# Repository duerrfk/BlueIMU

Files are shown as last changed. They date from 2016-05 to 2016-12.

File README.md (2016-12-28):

# What is BlueIMU?

BlueIMU is an Inertial Measurement Unit (IMU) with 6 degrees of freedom and Bluetooth connectivity (serial port profile / SPP). 

The main features of BlueIMU are:

* Based on inexpensive, easily available hardware components, namely, the 6 degrees of freedom GY521 IMU module featuring an InvenSense MPU-6050 sensor, the HC06 Bluetooth module, and an Atmega328P microcontroller. 
* Runs from a single cell LiPo battery. An overdischarge protection is included in the design. 
* Raw sensor values can be transmitted at sampling rates of 200 Hz and higher through a 230400 Baud wireless serial connection (Bluetooth SPP).
* The BlueIMU software is based on the Arduino IDE and can be easily modified.
* Fully open source hardware (circuit board / PCB) and software design.
* Sample application with Kalman filter for calculating attitude (pitch and roll) included. 

The following image shows the BlueIMU board. The GY521 IMU module is the little blue board on the left; the green board is the HC06 Bluetooth module.

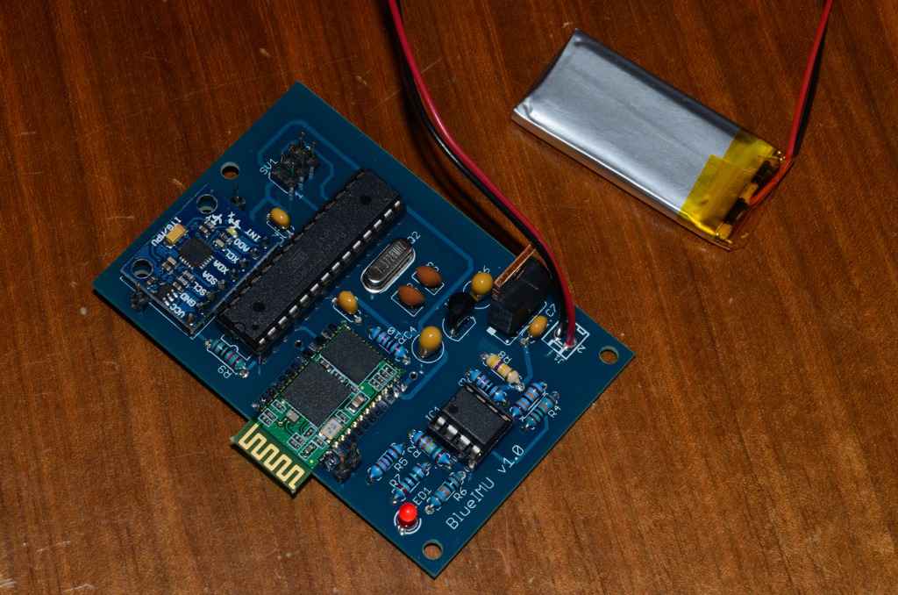
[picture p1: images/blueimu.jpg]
BlueIMU


Note that BlueIMU uses a 6 degrees of freedom IMU with a 3 axes accelerometer and 3 axes gyroscope, but without a magnetometer (compass). This is sufficient for sensing the pitch and roll, for instance, for controlling the attitude of a drone. However, we cannot sense the yaw to navigate a drone. However, the design could be easily adapted to use a 9 degrees of freedom IMU such as the InvenSense MPU-9250 on the GY-9250 module (GY521 and GY-9250 both use I2C for connecting to the MCU, but the GY-9250 requires 10 instead of 8 header pins to connect to the BlueIMU board).
 
# Why Yet Another IMU?

Many wireless IMUs today are based on Bluetooth Low Energy (BLE). Although BLE is optimized for very low energy consumption, it lacks support for higher data rates and low latency as required by sensors at higher sampling rates. In particular, the minimum connection interval of 7.5 ms inherently limits the sampling rate of wireless BLE sensors to about 133 Hz, and together with the small frames of only 20 bytes payload, the data rate is limited. Therefore, BLE is a great technology if you strive for years of battery lifetime at moderate data rates, however, for higher data rates and sensor sampling rates, standard Bluetooth is the better choice.

Therefore, BlueIMU uses standard Bluetooth supporting higher data rates (230400 Baud serial connection) to allow for higher sensor sampling rates at 200 Hz and higher.

# Hardware Design

The design of the BlueIMU circuit board (PCB) can be found in folder `pcb` (Eagle schematics and board design as well as Gerber files for production at a PCB house are included). 
  
BlueIMU is based on easily available low-cost components such as the GY521 IMU featuring a 6 degrees of freedom (3x accelerometer, 3x gyroscope) InvenSense MPU-6050 sensor, a HC06 Bluetooth module, and an Atmega328P microcontroller (MCU), which is well-supported by the popular Arduino platform.

The following images shows the schematic of the BlueIMU board.

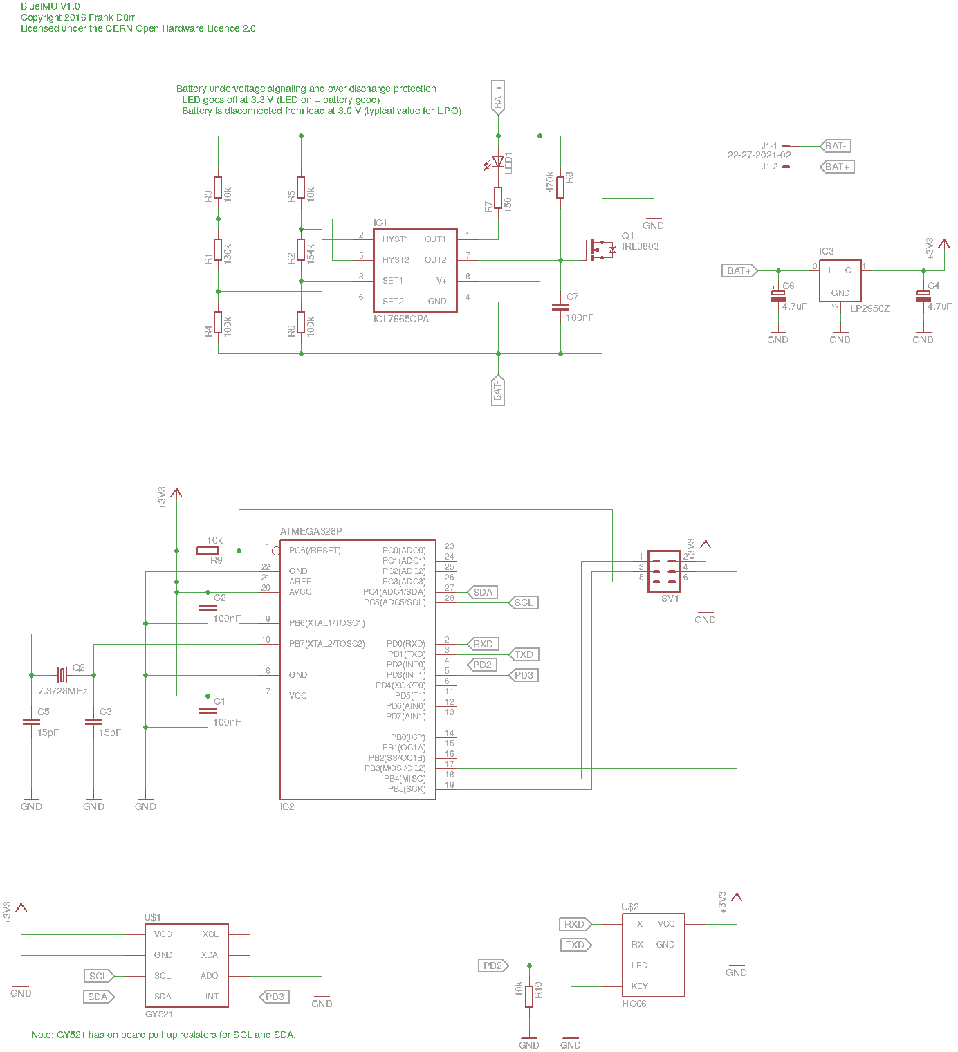
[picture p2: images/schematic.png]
Schematic


The Atmega328P MCU runs at 7.3728 MHz to allow for a perfect timing of the 230400 Baud serial connection to the HC06 Bluetooth module (230400 = 7.3728 MHz/32). Besides the serial connection, the HC06 module signals the Bluetooth connection state through a pin changing with a period of 750 ms while not connected and being constantly high while connected. Note that you need to porgram the HC06 module to use 230400 Baud using AT commands sent via the (wired) serial connection to the module (details can be found in the HC06 documentation).

A 6 pin connector is used to connect an in-system programmer with the following common pinout:

```
MISO <-- 1 2 --> VCC
SCK <--  3 4 --> MOSI
RST <--  5 6 --> GND
```

The GY521 module is connected through I2C to the MCU. It is soldered to the BlueIMU board using a 8 pin header providing for a rigid physical connection of the IMU to the BlueIMU board.

An overdischarge protection is included using the MAXIM ICL7665 voltage monitor. The MCU, IMU, and Bluetooth module will be disconnected from power at about 3.0 V. At about 3.3 V, the red LED (charge indicator) goes off to signal a low battery (the GY521 module has another onboard LED to show that the board is still running down to 3.0 V).  

## Preparing the Atmega328P (Programming Fuses)

Program the following fuses (note that "1" means fuse *not* programmed; "0" means fuse programmed):
  
* CKSEL = 1101, SUT 01: external crystal oscillator 3-8 MHz with fast startup times (BOD is enabled).
* CKDIV8 = 1: don't divide clock internally by 8.
* SPIEN = 0: enable serial programming.
* BODLEVEL = 101: brown-out detection set to 2.7 V.
* BOOTRST = 1: boot reset vector not enabled.
* RSTDISBL = 1: external reset not disabled.

This results in the following fuse bytes: 

* Low = 0xDD
* High = 0xD9
* Extended = 0x05

The MCU can be programmed using avrdude as follows:

```
$ sudo avrdude -c usbasp -p m328p -U lfuse:w:0xdd:m -U hfuse:w:0xd9:m -U efuse:w:0x05:m
```

## Flashing the Raw Transmitter Software

In folder `src/transmitter-raw` you find the raw transmitter software, which programs the BlueIMU to transmit raw measurements from the 3 axes accelerometer and 3 axes gyroscope of the MPU6050 IMU via Bluetooth serial profile (SPP). This software is implemented for the Arduino platform (tested with Arduino IDE 1.6.6) using the MPU6050 and I2C libraries by Jeff Rowberg.

In folder `arduino_board_definition` you find the corresponding board definition for the Atmega328P MCU running at 7.3728 MHz. Copy this directory into the folder `hardware` in your Arduino sketchbook.

Then, compile the Arduino sketch from folder `src/transmitter-raw`. This generates a hex file for the Atmega328P MCU. This hex file is a little bit hidden in the temporary build directory of the Arduino IDE. If you use Linux  and Arduino IDE 1.6, have a look at the `/tmp`  directory. After hitting the  compile button in the Arduino IDE, search for the latest hex file called  `transmitte-raw.cpp.hex` in a temporary directory named `/tmp/build...`. If you have found the hex file, you can flash it using avrdude:

```
$ sudo avrdude -p m328p -c usbasp -v -U flash:w:transmitter-raw.cpp.hex
```

## Data Format

Raw sensor data is transmitted over a Bluetooth serial connection. The transmitted data stream consists of records of the following format:

* Byte 0..1: Start of Record: 0x5A, 0xA5
* Byte 2..3: accelerometer X (16 bit signed int)  
* Byte 4..5: accelerometer Y (16 bit signed int)
* Byte 6..7: accelerometer Z (16 bit signed int)
* Byte 8..9: gyro X (16 bit signed int)
* Byte 10..11: gyro Y (16 bit signed int)
* Byte 12..13: gyro Z (16 bit signed int)
* Byte 14..17: sample time stamp (32 bit unsigned integer) in milliseconds since boot time
* Byte 18..19: 16 bit checksum

All 16 bit words are transmitted in Big Endian format (high byte first, low byte second). 

## Interpreting Raw Values

Values from sensors are transmitted as raw signed 16 bit values. The values can be translated to g and deg/s, respectively, depending on the configured sensor sensitivities (+-2g, +-4g, +-8g, +-16g; +-250 deg/s, +-500 deg/s, +- 1000 deg/s, +-2000 deg/s). The following resolutions are supported by the MPU6050 IMU:

* accelerometer: 16384, 8192, 4096, 2048 LSB / g
* gyro: 131, 65.5, 32.8, and 16.5 LSB / (deg/s) 

Please have a look at the manual of the MPU6050 for further details.

## Checksum 

The checksum consists of the ones' complement of the ones' complement sum of the 16-bit words, similar to the calculation of the checksum of IP headers. For detailed information on how to calculate the checksum, please have a look at the code. 

## Sampling Rate

The sampling rate can be adjusted by the SAMPLING_PERIOD definition.

## Low-pass Filter

The MPU 6050 features a low-pass filter. You can set the filter by defining DLPF according to the following table:

             |   ACCELEROMETER    |           GYROSCOPE
    DLPF_CFG | Bandwidth | Delay  | Bandwidth | Delay  | Sample Rate
    ---------+-----------+--------+-----------+--------+-------------
    0        | 260Hz     | 0ms    | 256Hz     | 0.98ms | 8kHz
    1        | 184Hz     | 2.0ms  | 188Hz     | 1.9ms  | 1kHz
    2        | 94Hz      | 3.0ms  | 98Hz      | 2.8ms  | 1kHz
    3        | 44Hz      | 4.9ms  | 42Hz      | 4.8ms  | 1kHz
    4        | 21Hz      | 8.5ms  | 20Hz      | 8.3ms  | 1kHz
    5        | 10Hz      | 13.8ms | 10Hz      | 13.4ms | 1kHz
    6        | 5Hz       | 19.0ms | 5Hz       | 18.6ms | 1kHz
    7        |   -- Reserved --   |   -- Reserved --   | Reserved

# Connecting a Linux Host to BlueIMU over Bluetooth

You can connect a Linux host to the BlueIMU board via Bluetooth as follows:

Step 1: Find the BlueIMU device 

```
$ hcitool scan
Scanning ...
	00:11:12:31:04:12	BlueIMU
```

Step 2: Pairing Linux host and BlueIMU device:

```
$ bluetooth-agent 1234 00:11:12:31:04:12
```

Step 3: Add device profile

```
$ sudo nano /etc/bluetooth/rfcomm.conf
```

Add the following section:

```
rfcomm1 {
  bind no;
  device 00:11:12:31:04:12;
  channel 1;
  comment "Blue IMU serial Port";
}
```

Connect host to BlueIMU device: 

```
$ rfcomm connect 1
```

Now, you should have a serial device called `/dev/rfcomm1` that you can open with your application. For instance, you can use screen to log data as follows:

```
$ screen -L /dev/rfcomm1
```

# Kalman Filter

In folder `src/receiver-attitude` you find a sample application for Linux implementing a Kalman filter to calculate the attitude (pitch and roll) and logging raw sensor values and Kalman filter values (pitch, roll, estimated gyro bias) to a file as comma-separate values. Note that the GY521 IMU does not feature a magnetometer (compass), thus, we cannot easily detect the absolute heading (yaw). 

You can compile this application with the following commands:

```
$ cd src/receiver-attitude
$ make 
```

Then you start it as follows:

```
$ ./receiver-attitude -d /dev/rfcomm1 -o out.csv
```

The Kalman filter uses the following equations:

State vector (phi is the angle; phidot is the angular velocity; bias is the bias of angular velocity (gyro bias)): 

```
    [ phi  ] 
x = [phidot]
    [ bias ] 
```

State equation:

```
x(k) = F(k)*x(k-1) + omega(k)
```

with

```
       [1 t_delta -t_delta]
F(k) = [0    1        0   ]
       [0    0        1   ]
```

This implementation assumes no control input model (B). Instead, a normally distributed random angular acceleration (phidotdot) is introduced modeling the effect of external forces like motors as part of the random process noise (omega):

```
           [t_delta**2/2]
omega(k) = [  t_delta   ] * phidotdot
           [     0      ]
```

Covariance matrix Q of normally distributed random process noise omega ~ N(0,Q):

```
Q = G*Gtrans*sigma_phidotdot**2 

    [t_delta**4/4  t_delta**3/2  0]                        [ 0 0 0 ]
  = [t_delta**3/2   t_delta**2   0] * sigma_phidotdot**2 + [ 0 0 0 ] * sigma_bias**2 
    [      0             0       0]                        [ 0 0 1 ]
```

Moreover, we assume that we can measure the angle from the IMU acceleration (phi_m) and the angular velocity (phidot_m) from the gyroscope. However, we cannot measure the gyro bias. Measurements are modeled as independent normally distributed random variables to account for measurement noise. The covariance matrix R of normally distributed random measuring noise v ~ N(0,R) is defined as:

```
    [sigma_phi_m**2         0         ]
R = 
    [     0          sigma_phidot_m**2]
```

Sample data of a stationary IMU and an IMU attached to a pendulum can be found in folder `sample-data`. 

The following plot shows the angle of a pendulum in radians over time as calculated by the Kalman filter:

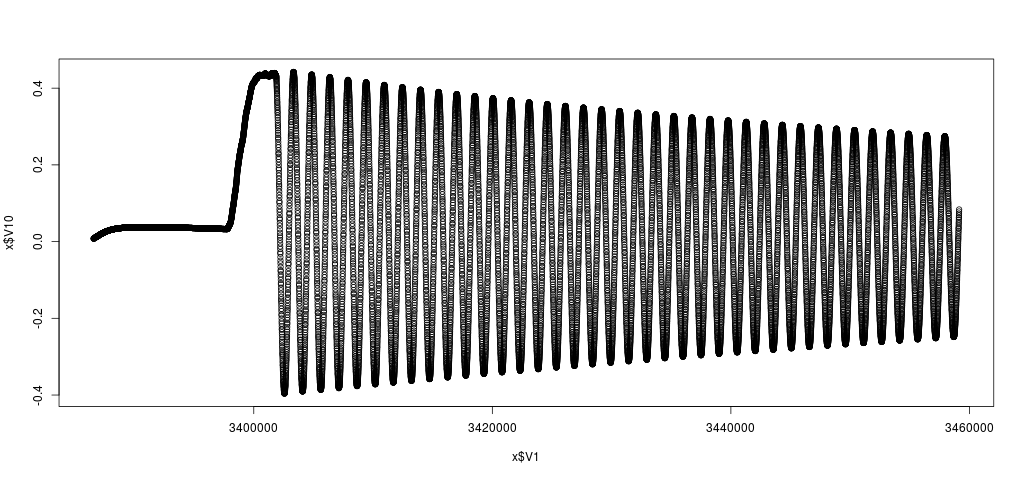
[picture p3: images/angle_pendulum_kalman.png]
Angle pendulum Kalman


As a comparison, here the angle in radians over time calculated directly from the accelerometer without Kalman filter, i.e., without fusing measurements from accelerometer and gyroscope:

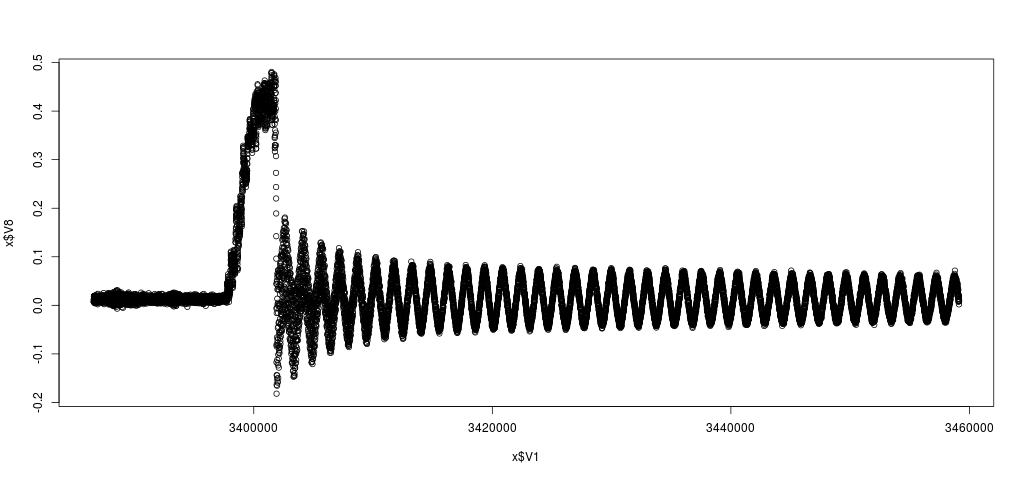
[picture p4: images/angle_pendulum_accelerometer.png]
Angle pendulum accelerometer


Observer how the angle calculated just from acceleration is only correct while the object is at rest and clearly wrong when the pendulum moves such that gravity cannot be easily distinguished anymore from the acceleration caused by centripetal force. In that case, the Kalman filter can use the angular velocity to predict the angle leading to much more accurate results.

# License

The BlueIMU software (contents of folders `src`) is licensed under the Apache License, Version 2.0.

The BlueIMU hardware documentation (contents of folder `pcb`) is licensed under the CERN Open Hardware Licence, Version 1.2

Both licenses are included in the repository in the files `LICENSE-SOFTWARE` and `LICENSE-HARDWARE`, respectively.

The BlueIMU software uses the I2Cdev device library and MPU-6050 code by Jeff Rowberg licensed under the MIT license.

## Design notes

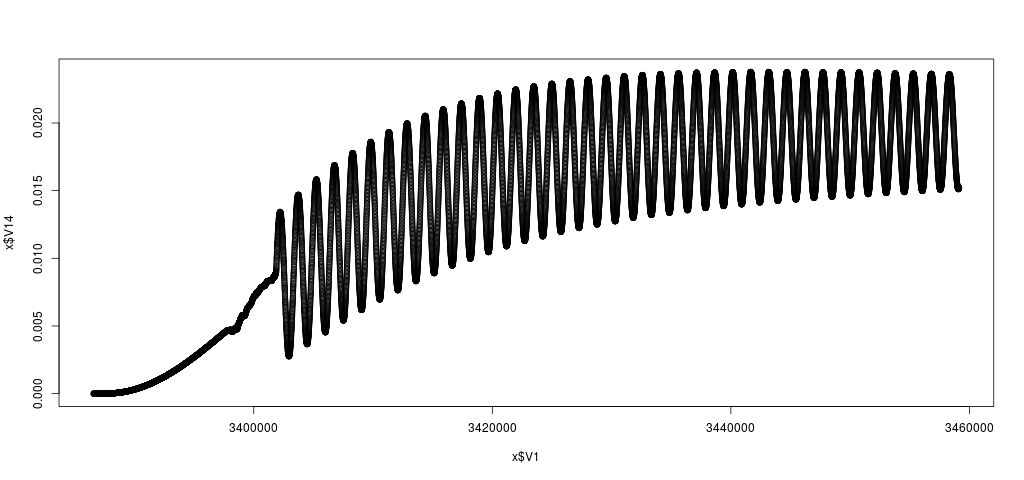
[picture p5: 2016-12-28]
images/gyro_bias_pendulum.png

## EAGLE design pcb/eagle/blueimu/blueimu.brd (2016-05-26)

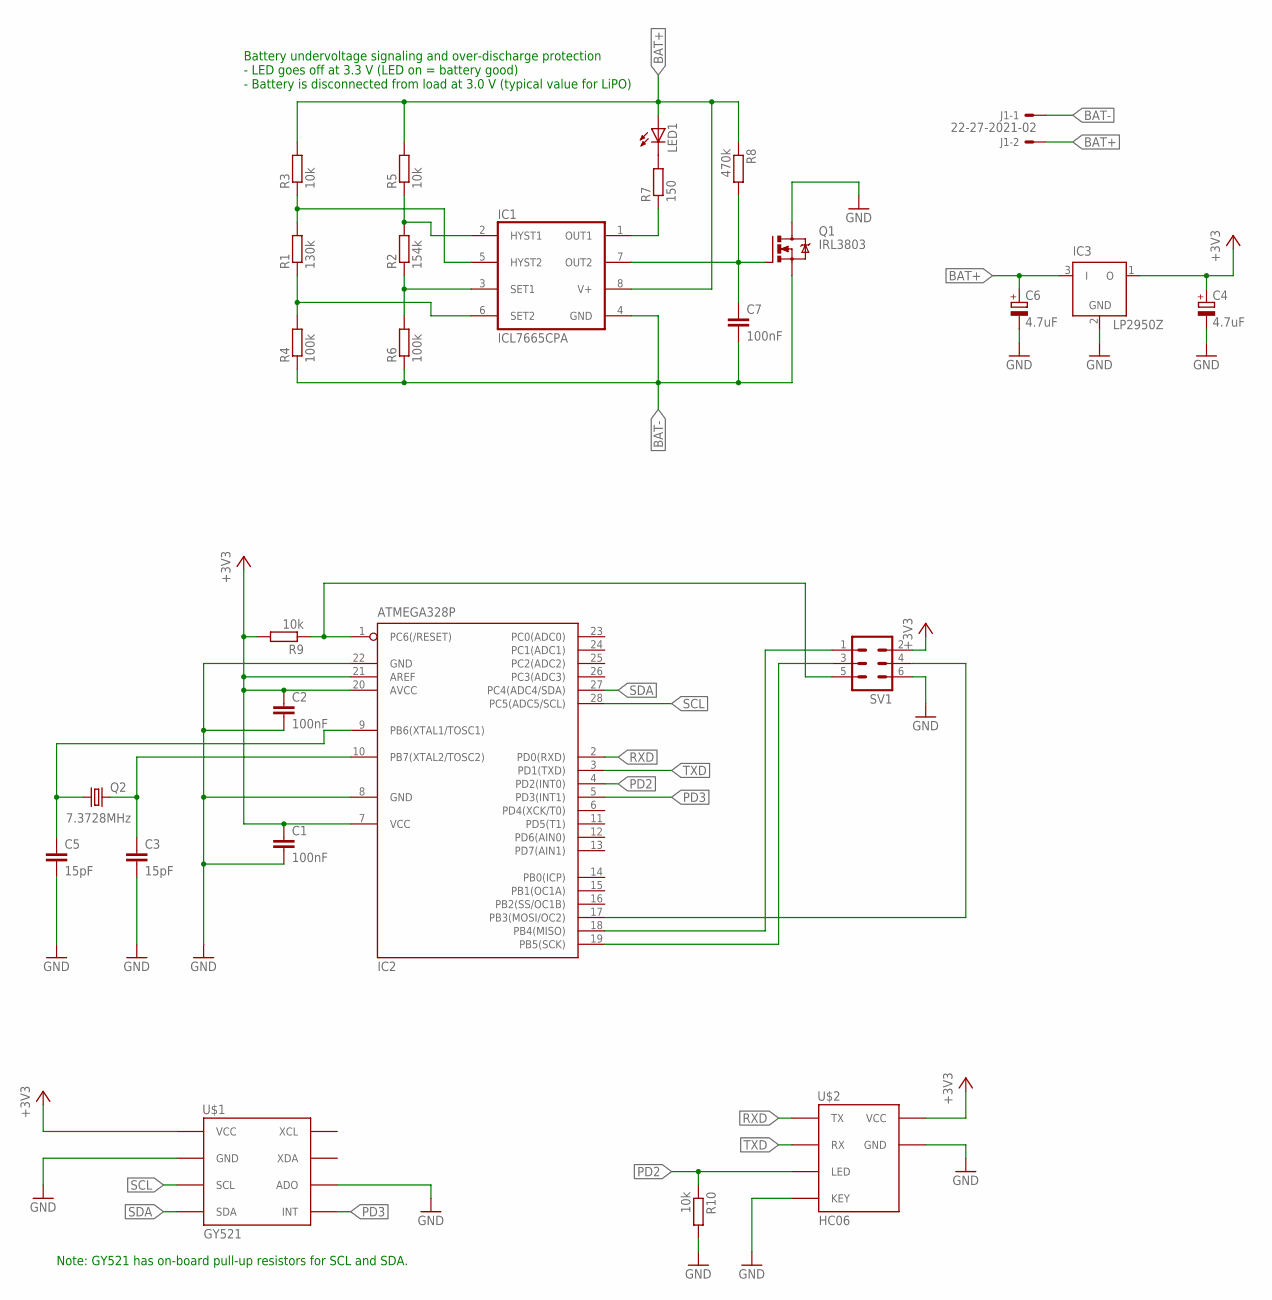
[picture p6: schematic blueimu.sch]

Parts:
C1, C2, C7: 100nF; C050-024X044
C3, C5: 15pF; C025-025X050
C4, C6: 4.7uF; E2,5-5
IC1: ICL7665CPA; DIL08
IC2: ATMEGA328P; DIL28-3
IC3: LP2950Z; TO92
J1: 22-27-2021-02; 6410-02
LED1: LED3MM
Q1: IRL3803; TO220BV
Q2: 7.3728MHz; HC49U-V
R1: 130k; 0207/7
R2: 154k; 0207/7
R3, R5, R9, R10: 10k; 0207/7
R4, R6: 100k; 0207/7
R7: 150; 0207/7
R8: 470k; 0207/7
SV1: MA03-2
U$1: GY521
U$2: HC06

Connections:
+3V3: C1.1, C2.1, C4.+, IC2.7 (VCC), IC2.20 (AVCC), IC2.21 (AREF), IC3.1 (O), R9.2, SV1.2, U$1.VCC, U$2.VCC
BAT+: C6.+, IC1.8 (V+), IC3.3 (I), J1.2, LED1.A, R3.2, R5.2, R8.1
BAT-: C7.2, IC1.4 (GND), J1.1, Q1.S, R4.1, R6.1
GND: C1.2, C2.2, C3.2, C4.-, C5.2, C6.-, IC2.8 (GND), IC2.22 (GND), IC3.2 (GND), Q1.D, R10.2, SV1.6, U$1.ADO, U$1.GND, U$2.GND, U$2.KEY
unnamed: LED1.K (C), R7.2
unnamed: IC1.1 (OUT1), R7.1
unnamed: IC1.2 (HYST1), R2.2, R5.1
unnamed: IC1.3 (SET1), R2.1, R6.2
unnamed: IC2.18 (PB4(MISO)), SV1.1
unnamed: IC2.19 (PB5(SCK)), SV1.3
unnamed: IC2.17 (PB3(MOSI/OC2)), SV1.4
unnamed: IC2.1 (PC6(/RESET)), R9.1, SV1.5
unnamed: C7.1, IC1.7 (OUT2), Q1.G, R8.2
unnamed: C3.1, IC2.10 (PB7(XTAL2/TOSC2)), Q2.2
unnamed: IC1.6 (SET2), R1.1, R4.2
unnamed: IC1.5 (HYST2), R1.2, R3.1
unnamed: C5.1, IC2.9 (PB6(XTAL1/TOSC1)), Q2.1
PD2: IC2.4 (PD2(INT0)), R10.1, U$2.LED
PD3: IC2.5 (PD3(INT1)), U$1.INT
RXD: IC2.2 (PD0(RXD)), U$2.TX
SCL: IC2.28 (PC5(ADC5/SCL)), U$1.SCL
SDA: IC2.27 (PC4(ADC4/SDA)), U$1.SDA
TXD: IC2.3 (PD1(TXD)), U$2.RX

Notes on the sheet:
Note: GY521 has on-board pull-up resistors for SCL and SDA.
Battery undervoltage signaling and over-discharge protection - LED goes off at 3.3 V (LED on = battery good) - Battery is disconnected from load at 3.0 V (typical value for LiPO)

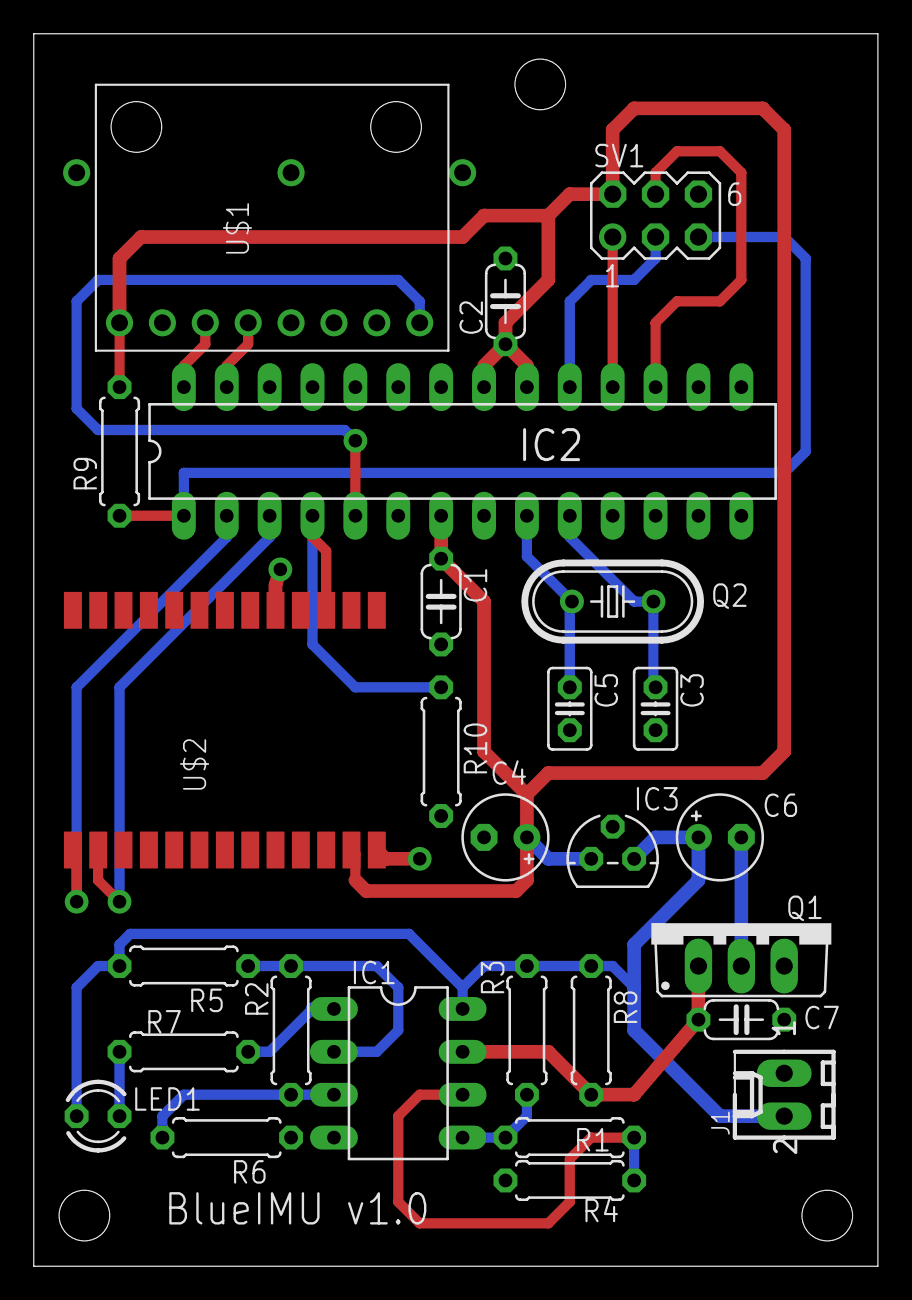
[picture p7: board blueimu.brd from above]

Board: 2 copper layers, 50.0 x 73.0 mm, 27 parts (0 on the bottom side), 23 nets.

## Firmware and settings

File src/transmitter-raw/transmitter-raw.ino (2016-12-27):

/**
 * This file is part of BlueIMU.
 * 
 * Copyright 2016 Frank Duerr
 *
 * Licensed under the Apache License, Version 2.0 (the "License");
 * you may not use this file except in compliance with the License.
 * You may obtain a copy of the License at
 * 
 * http://www.apache.org/licenses/LICENSE-2.0
 * 
 * Unless required by applicable law or agreed to in writing, software
 * distributed under the License is distributed on an "AS IS" BASIS,
 * WITHOUT WARRANTIES OR CONDITIONS OF ANY KIND, either express or implied.
 * See the License for the specific language governing permissions and
 * limitations under the License.
 */
 
#include <TimerOne.h>
#include <Wire.h>
#include "I2Cdev.h"
#include "MPU6050.h"

// The pin where the LED output of the Bluetooth module is connected.
// This pin is used to detect the connection status (blinking = disconnected;
// constantly on = connected). This pin supports level interrupts to listen 
// for connection status changes.
#define PIN_LED 2

// Sampling period in microseconds.
// Note: Depending on the sampling interval, you should set the digital 
// low-pass filter. Filter cut-off frequencies should not be too low for 
// a given sampling period (see DLPF definition).
#define SAMPLING_PERIOD 5000

// The baud rate of the serial connection to the Bluetooth module. 
// The MCU is running at 7.3728 MHz. Thus, 230400 baud = 7.3728/32 allows for 
// perfect timing for serial communication. 
#define BAUD_RATE 230400

// The sensitivity and value range of the accelerometer as defined by the
// following table:
//
// AFS_SEL | Full Scale Range | LSB Sensitivity
// --------+------------------+----------------
// 0       | +/- 2g           | 16384 LSB/g
// 1       | +/- 4g           | 8192 LSB/g
// 2       | +/- 8g           | 4096 LSB/g
// 3       | +/- 16g          | 2048 LSB/g
#define RANGE_ACCEL 1

// The sensitivity and value range of the gyroscope as defined by the
// following table:
//
// FS_SEL | Full Scale Range   | LSB Sensitivity
// -------+--------------------+----------------
// 0      | +/- 250 degrees/s  | 131 LSB/deg/s
// 1      | +/- 500 degrees/s  | 65.5 LSB/deg/s
// 2      | +/- 1000 degrees/s | 32.8 LSB/deg/s
// 3      | +/- 2000 degrees/s | 16.4 LSB/deg/s
#define RANGE_GYRO 1

// Configuration of digital low pass filter of IMU according to the
// following table:
//
//          |   ACCELEROMETER    |           GYROSCOPE
// DLPF_CFG | Bandwidth | Delay  | Bandwidth | Delay  | Sample Rate
// ---------+-----------+--------+-----------+--------+-------------
// 0        | 260Hz     | 0ms    | 256Hz     | 0.98ms | 8kHz
// 1        | 184Hz     | 2.0ms  | 188Hz     | 1.9ms  | 1kHz
// 2        | 94Hz      | 3.0ms  | 98Hz      | 2.8ms  | 1kHz
// 3        | 44Hz      | 4.9ms  | 42Hz      | 4.8ms  | 1kHz
// 4        | 21Hz      | 8.5ms  | 20Hz      | 8.3ms  | 1kHz
// 5        | 10Hz      | 13.8ms | 10Hz      | 13.4ms | 1kHz
// 6        | 5Hz       | 19.0ms | 5Hz       | 18.6ms | 1kHz
// 7        |   -- Reserved --   |   -- Reserved --   | Reserved
//
// For instance, if you choose value 6, signals with frequency > 5 Hz
// will be cut-off.
#define DLPF 0

// Start of frame pattern.
const uint8_t start_of_frame[] = {0x5A, 0xA5};

volatile enum State {disconnected, connected} state = disconnected;  

volatile bool is_sample_due = false;

// The GY-521 board has a pull-down resistor connected to AD0,
// so the I2C address is 0x68 (default). Change to 0x69 if a pull-up 
// resistor is used instead.
//MPU6050 imu(0x69);
MPU6050 imu;

/**
 * Calculation of 16 bit checksum. 
 * 
 * This implementation uses the same algorithm as IP to calculate
 * IP header checksums. 
 * 
 * Performing the same calculation over the data *and*
 * checksum should yield 0 in case of no error.
 * 
 * The following code is adapted from Gary R. Wright, W. Richard Stevens: 
 * TCP/IP Illustrated, Volume 2 (there called a "naive implementation"; 
 * you can also find an optimized implementation there).
 */
uint16_t checksum(const uint8_t *data, size_t len)
{
     // Note that we do not need to consider byte order. From RFC 1071: 
     // "The sum of 16-bit integers can be computed in either byte order."

     uint32_t sum = 0;
     uint16_t *words = (uint16_t *) data;

     while (len > 1) {
         sum += *(words)++;
         if (sum&0x80000000)
             sum = (sum&0xFFFF) + (sum>>16);
         len -= 2;
     }

     if (len)
         sum += *((uint8_t *) words);
     
     while (sum>>16)
         sum = (sum & 0xFFFF) + (sum >> 16);

     return ~sum;
}

/**
 * Marshal data and send frame over serial connection to Bluetooth module.
 * 
 * All 16 bit values are sent in Big Endian (network) byte order.
 */
void send_frame(int16_t accelX, int16_t accelY, int16_t accelZ,
                int16_t gyroX, int16_t gyroY, int16_t gyroZ, uint32_t timestamp) 
{
    uint8_t frame[20];

    // Add start of frame
    frame[0] = start_of_frame[0];
    frame[1] = start_of_frame[1];

    // Add values in Big Endian byte order
    frame[2] = (accelX>>8);
    frame[3] = (accelX&0xFF);

    frame[4] = (accelY>>8);
    frame[5] = (accelY&0xFF);

    frame[6] = (accelZ>>8);
    frame[7] = (accelZ&0xFF);

    frame[8] = (gyroX>>8);
    frame[9] = (gyroX&0xFF);

    frame[10] = (gyroY>>8);
    frame[11] = (gyroY&0xFF);
    
    frame[12] = (gyroZ>>8);
    frame[13] = (gyroZ&0xFF);

    frame[14] = (timestamp>>24);
    frame[15] = ((timestamp>>16)&0xFF);
    frame[16] = ((timestamp>>8)&0xFF);
    frame[17] = (timestamp&0xFF);
    
    // Add checksum
    uint16_t csum = checksum(frame, 18);
    // The IP checksum algorithm works for any byte order. 
    // However, we need to sent out the 16 bit checksum in the 
    // byte order of the platform. Atmega uses Little Endian
    // byte order, so we need to send the low byte first.
    frame[18] = (csum&0xFF);
    frame[19] = (csum>>8);

    // Send frame
    Serial.write(frame, 20);
}

/**
 * Called in case of fatal error preventing continuation.
 * 
 * This function will never return and signal a fatal error over
 * Bluetooth by sending empty frames (start of frame sequence only) 
 * in an endlessly.
 */
void die()
{
    uint8_t frame[2];
    frame[0] = start_of_frame[0];
    frame[1] = start_of_frame[1];
    
    while (1) {
        // Send empty frames to signal exception
        Serial.write(frame, 2);
        delay(1000); 
    }
}

/**
 * Initial setup.
 */
void setup() 
{
    // Give components (IMU module, Bluetooth module) some time to start.
    delay(2000);
    
    Serial.begin(BAUD_RATE, SERIAL_8N1); 

    // Initialize sampling timer. The timer is only active
    // when a connection is made via Bluetooth. So we only
    // initialize the timer interval here and start the timer later.
    Timer1.initialize(SAMPLING_PERIOD);

    // With this pin, the Bluetooth module signals the connection status.
    pinMode(PIN_LED, INPUT);

    // Initialize IMU

    // Init I2C
    Wire.begin();
    
    // Initialize IMU device.
    imu.initialize();
    imu.setFullScaleGyroRange(RANGE_GYRO);
    imu.setFullScaleAccelRange(RANGE_ACCEL);
    
    // Set digital low-pass filter (DLPF)
    //          |   ACCELEROMETER    |           GYROSCOPE
    // DLPF_CFG | Bandwidth | Delay  | Bandwidth | Delay  | Sample Rate
    // ---------+-----------+--------+-----------+--------+-------------
    // 0        | 260Hz     | 0ms    | 256Hz     | 0.98ms | 8kHz
    // 1        | 184Hz     | 2.0ms  | 188Hz     | 1.9ms  | 1kHz
    // 2        | 94Hz      | 3.0ms  | 98Hz      | 2.8ms  | 1kHz
    // 3        | 44Hz      | 4.9ms  | 42Hz      | 4.8ms  | 1kHz
    // 4        | 21Hz      | 8.5ms  | 20Hz      | 8.3ms  | 1kHz
    // 5        | 10Hz      | 13.8ms | 10Hz      | 13.4ms | 1kHz
    // 6        | 5Hz       | 19.0ms | 5Hz       | 18.6ms | 1kHz
    // 7        |   -- Reserved --   |   -- Reserved --   | Reserved
    imu.setDLPFMode(DLPF);

    unsigned int try_count = 0;
    while (1) {
        // Verify connection
        if (imu.testConnection()) {
            // All fine
            break;
        } else {
            try_count++;
        }
        if (try_count > 3)
            die();
        delay(1000);
    }
}

/**
 * Interrupt routing for checking communication status.
 * 
 * Disconnections are signalled by low-level on PIN_LED.
 */
void led_isr()
{
    // We are now disconneted and can deregister ISR until
    // another connection is made.
    detachInterrupt(digitalPinToInterrupt(PIN_LED));
    
    // Detach timer interrupt to stop sampling.
    Timer1.detachInterrupt();
    
    state = disconnected;
}

/**
 * Interrupt routine of sampling timer.
 */
void sampling_timer_isr()
{
    is_sample_due = true;
}

/**
 * Take a sample (accelerometer & gyro) and send
 * data to Bluetooth module for transmission.
 */
void take_sample_and_send()
{
    int16_t axi, ayi, azi;
    int16_t rxi, ryi, rzi;
    imu.getMotion6(&axi, &ayi, &azi, &rxi, &ryi, &rzi); 
    uint32_t t = millis();
    
    send_frame(axi, ayi, azi, rxi, ryi, rzi, t);  
}

void loop() 
{
    unsigned int high_count;
    switch (state) {
    case disconnected :
        // Wait for Bluetooth connection. 
        // While disconnected, the LED of the Bluetooth module blinks with a 
        // period of 750 ms. While connected, the LED is constantly on.
        // To detect a connection, we sample the LED with a frequency of 10 Hz.
        // If the LED pin remains high during an interval of 1 s, we assume 
        // that the Bluetooth module is connected. 
        high_count = 0;
        while (high_count < 10) {
            if (digitalRead(PIN_LED) == LOW)
                high_count = 0;
            else
                high_count++; 
            delay(100);
        }
        state = connected;
        // Start timer for sampling.
        // It's important to first attach the timer interrupt and then the level
        // interrupt, otherwise the timer interrupt might no get detached when the
        // level interrupt fires early.
        Timer1.attachInterrupt(sampling_timer_isr);
        // If the Bluetooth module LED pin goes low, the device is disconnected. 
        // To detect the disconnection, we use a level interrupt on the LED pin. 
        attachInterrupt(digitalPinToInterrupt(PIN_LED), led_isr, LOW);
        break;
    case connected:
        if (is_sample_due) {
            take_sample_and_send();
            is_sample_due = false;
        }
        break;
    }
}

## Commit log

2016-04-10 Initial check-in
    [blueimu.brd, blueimu.sch]
2016-04-11 Removed unnecessary pull-up resistor from serial line. Added pull-down resistor for LED output.
    [blueimu.brd, blueimu.sch]
2016-04-11 Cosmetic label changes.
    [blueimu.brd]
2016-05-15 Cosmetic changes to schematics and board layout
    [blueimu.brd, blueimu.sch]
2016-05-26 Added capacitor. Added Gerber files.
    [blueimu.brd, blueimu.sch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]
2016-06-12 Added copyright notice. Added MPU6050 driver files.
2016-06-12 Added timestamps to samples. Added readme for raw-transmitter.
2016-06-12 Fixed bug in frame generation
2016-06-13 Added board definition
2016-06-25 Fixed bugs in serial communication and checksum transmission. Added DEBUG flag.
    [transmitter-raw.ino]
2016-07-10 Kalman filter now also estimating gyro bias
2016-08-27 First working version of Kalman filter
2016-08-27 Added data from pendulum experiment
    [attitude-pendulum.csv]
2016-12-27 Added images, sample data, and extended README.
    [samples-pendulum.csv, samples-stationary.csv]
2016-12-27 Extended Readme.
    [attitude-pendulum.csv, blueimu.sch]
2016-12-28 Added plot for gyro bias estimation.
